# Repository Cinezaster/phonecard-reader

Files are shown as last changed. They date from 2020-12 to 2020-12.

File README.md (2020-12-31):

# Phonecard-reader

A phonecard reader that outputs the memory of a phonecard in hexadecimal via keystrokes

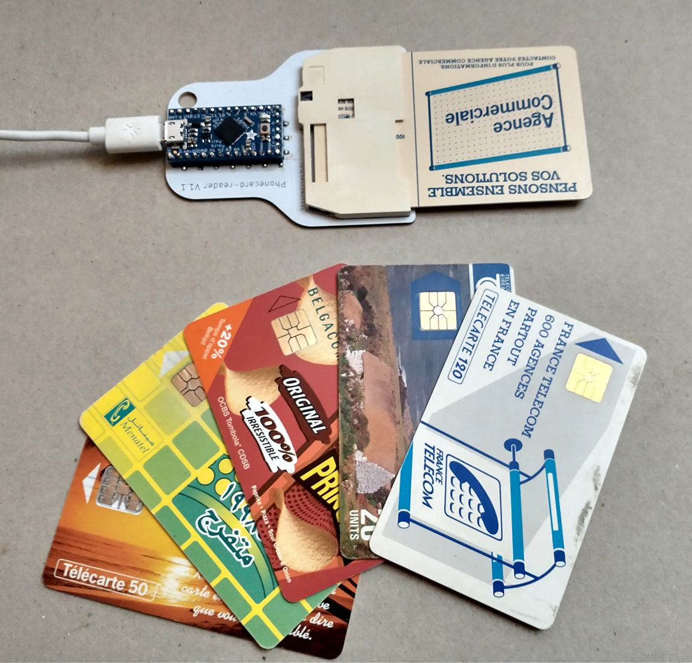
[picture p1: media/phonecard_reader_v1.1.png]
Phonecard reader pcb & cards phonecard reader & cards


## Requirements

- should read the memory of Gen 1 phonecards
- should read the memory of Gen 2 ISO 7816 phonecards
- should return the memory as a hex string to a computer or smartphone as keystrokes
- should check if memory can be read consistently

## Specs

- a 16pin card reader for iso 7816 and AFNOR type of cards: [RS-online](https://befr.rs-online.com/web/p/memory-card-connectors/0252585/)
- a 5V MCU with HID capacity like [arduino micro](https://store.arduino.cc/arduino-micro) or [Adafruit ItsyBitsy 32u4 5V](https://www.adafruit.com/product/3677)

## Hardware

A 1-Layer smd pcb.

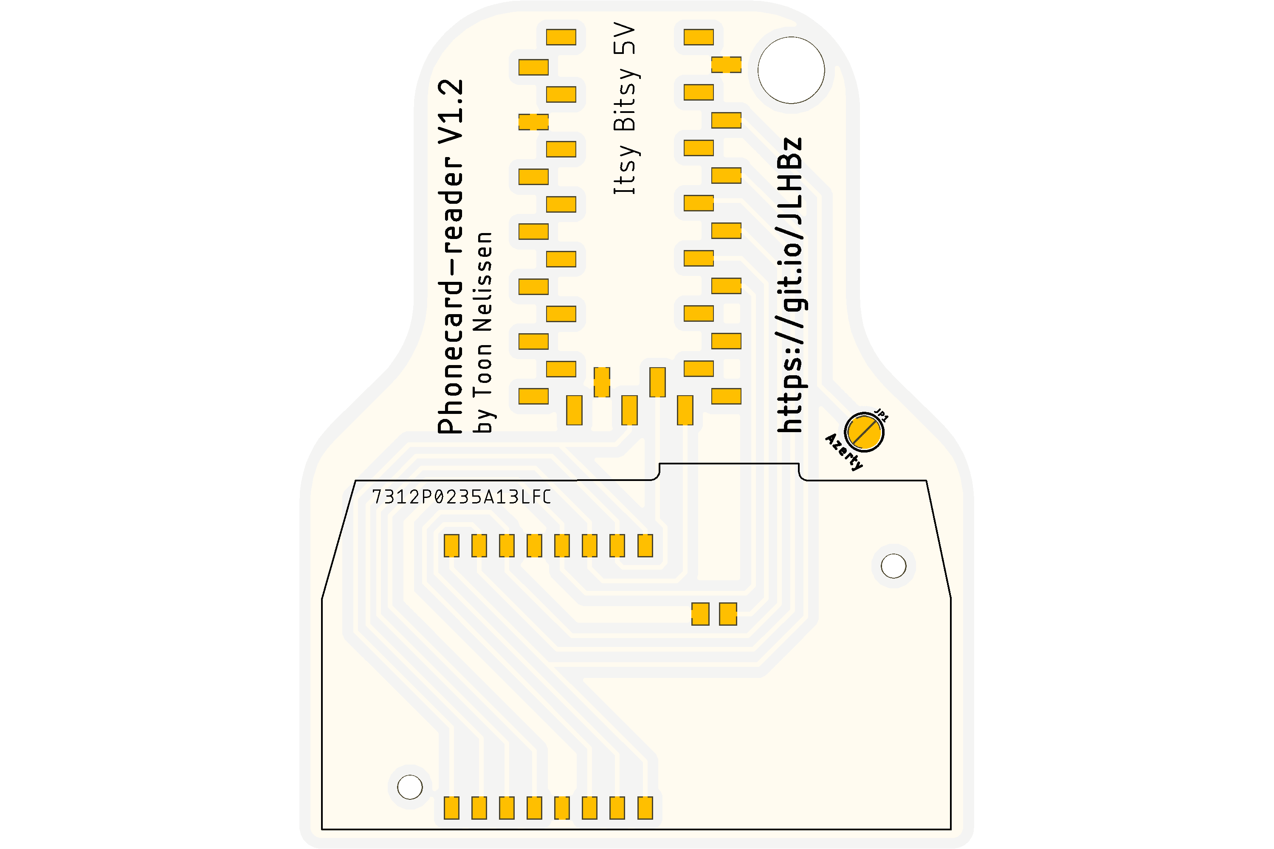
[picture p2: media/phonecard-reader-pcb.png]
Phonecard reader pcb phonecard reader pcb


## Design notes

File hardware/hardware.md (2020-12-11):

# Hardware

## MCU

Requirements are 5V and HID emulation this fits well with the **ATmega32U4**

- [Adafruit ItsyBitsy 32u4](https://www.adafruit.com/product/3677) (€8,40) *Cheapest*
- [SparkFun Qwiic Pro Micro - USB-C](https://www.sparkfun.com/products/15795) (€19) *surface mounted*
- [Teensy 2.0](https://www.pjrc.com/store/teensy.html) (€17)
- [Arduino MICRO](https://store.arduino.cc/arduino-micro) (€18)

## Card connector/ socket

We like to use a 16pin connector because of the AFNOR and ISO 7816 cards ([more info](https://www.sbprojects.net/knowledge/footprints/smart/index.php))

- [Amphenol fcicoonnect 7312P0235A13LFC](https://www.amphenol-icc.com/smart-card-7312p0235a13lf.html)

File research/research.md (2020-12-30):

# Research

## Cards spec info

- [http://www.smartcardsupply.com/Content/Cards/7816standard.htm](http://www.smartcardsupply.com/Content/Cards/7816standard.htm)
- [https://resources.infosecinstitute.com/topic/introduction-smartcard-security/](https://resources.infosecinstitute.com/topic/introduction-smartcard-security/)
- [https://github.com/arduinocodedog/Parallax-Smart-Card-Reader-Library-for-Arduino](https://github.com/arduinocodedog/Parallax-Smart-Card-Reader-Library-for-Arduino)
- [http://www.acornatom.nl/sites/oss/telkaart.htm](http://www.acornatom.nl/sites/oss/telkaart.htm)
- [https://hacktic.nl/magazine/2426.htm](https://hacktic.nl/magazine/2426.htm)
- [http://www.acbm.com/inedits/secrets-telecartes-3G.html](http://www.acbm.com/inedits/secrets-telecartes-3G.html)
- [how chips work (v1.18)](https://www.epanorama.net/documents/smartcard/how_chips_work.txt)
- [how chips work (v2.04)](www.pcbheaven.com/userpages/files/How_Phonecard_Smart_Cards_Work_3.txt)
- [http://matthieu.weber.free.fr/electronique/cartes_a_puces/index.html](http://matthieu.weber.free.fr/electronique/cartes_a_puces/index.html)
- [http://www.pcbheaven.com/userpages/How_Phonecard_Smart_Cards_Work/index.php?topic=worklog&p=0](http://www.pcbheaven.com/userpages/How_Phonecard_Smart_Cards_Work/index.php?topic=worklog&p=0)
- [http://www.tobiasfeigl.de/2015/12/23/arduino-atmel32u4-smart-card-reader-iso-7816-protocol-t1/](http://www.tobiasfeigl.de/2015/12/23/arduino-atmel32u4-smart-card-reader-iso-7816-protocol-t1/)
- [https://www.makomk.com/2011/02/25/iso-7816-smartcard-interface-for-arduino/](https://www.makomk.com/2011/02/25/iso-7816-smartcard-interface-for-arduino/)
- [http://www.smartcardsupply.com/PDF/DS_sle4432_42_0795.pdf](http://www.smartcardsupply.com/PDF/DS_sle4432_42_0795.pdf)
- [https://hackaday.com/2008/11/25/how-to-read-a-fedex-kinkos-smart-card-sle4442/](https://hackaday.com/2008/11/25/how-to-read-a-fedex-kinkos-smart-card-sle4442/)
- [http://col2000.free.fr/telecart/index.htm](http://col2000.free.fr/telecart/index.htm)
- [https://forum.arduino.cc/index.php?topic=91751.0](https://forum.arduino.cc/index.php?topic=91751.0)
- [Type of Smart Cards](https://www.sbprojects.net/knowledge/footprints/smart/index.php)

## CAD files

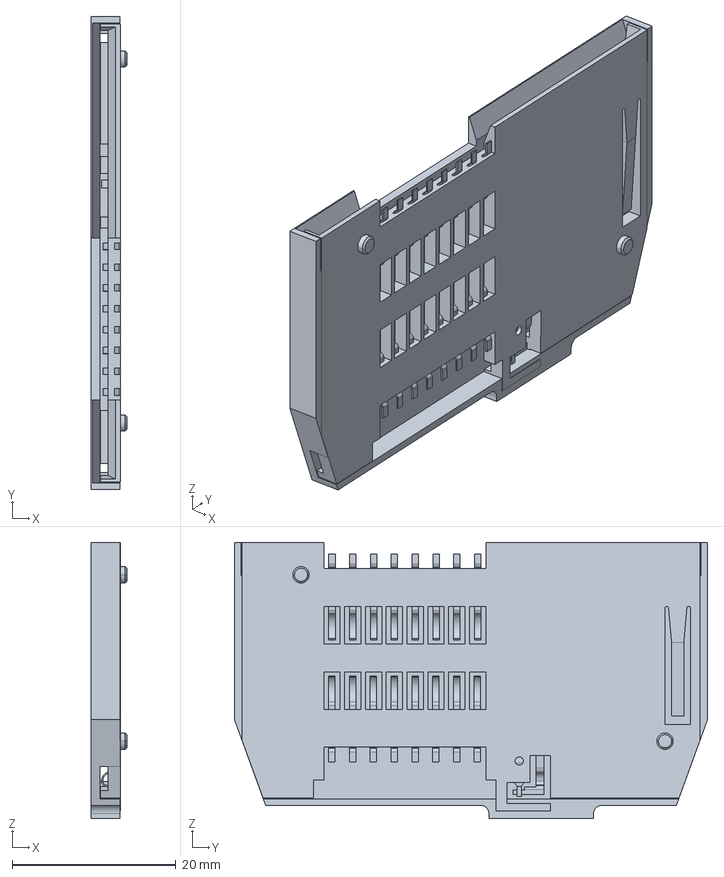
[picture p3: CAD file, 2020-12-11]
hardware/documentation/7312P0235A13LFC.stp
4.35 x 57.8 x 33.7 mm

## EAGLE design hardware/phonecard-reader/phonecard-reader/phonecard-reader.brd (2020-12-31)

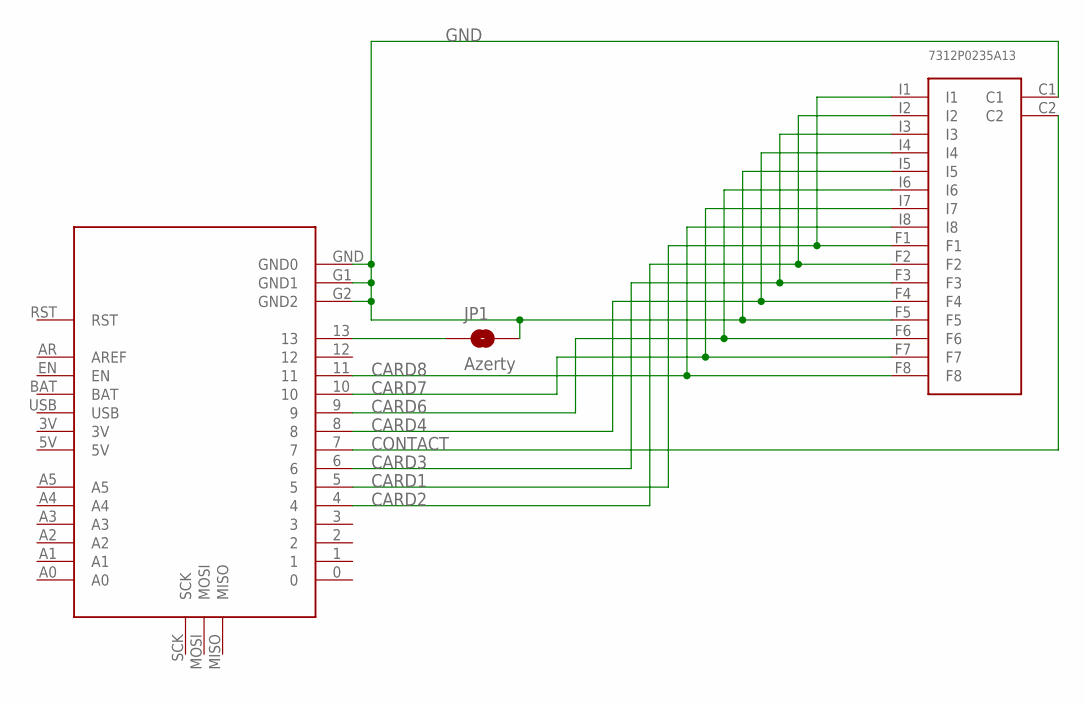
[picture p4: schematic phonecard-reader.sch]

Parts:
JP1: Azerty; SMT-JUMPER_2_NO_SILK_ROUND
U$1: Itsy Bitsy 5V; ITSY_BITSY_SMD
U$2: 7312P0235A13LFC; 7312P0235A13

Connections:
CARD1: U$1.5, U$2.F1, U$2.I1
CARD2: U$1.4, U$2.F2, U$2.I2
CARD3: U$1.6, U$2.F3, U$2.I3
CARD4: U$1.8, U$2.F4, U$2.I4
CARD6: U$1.9, U$2.F6, U$2.I6
CARD7: U$1.10, U$2.F7, U$2.I7
CARD8: U$1.11, U$2.F8, U$2.I8
CONTACT: U$1.7, U$2.C2
GND: JP1.2, U$1.G1 (GND1), U$1.G2 (GND2), U$1.GND (GND0), U$2.C1, U$2.F5, U$2.I5
unnamed: JP1.1, U$1.13

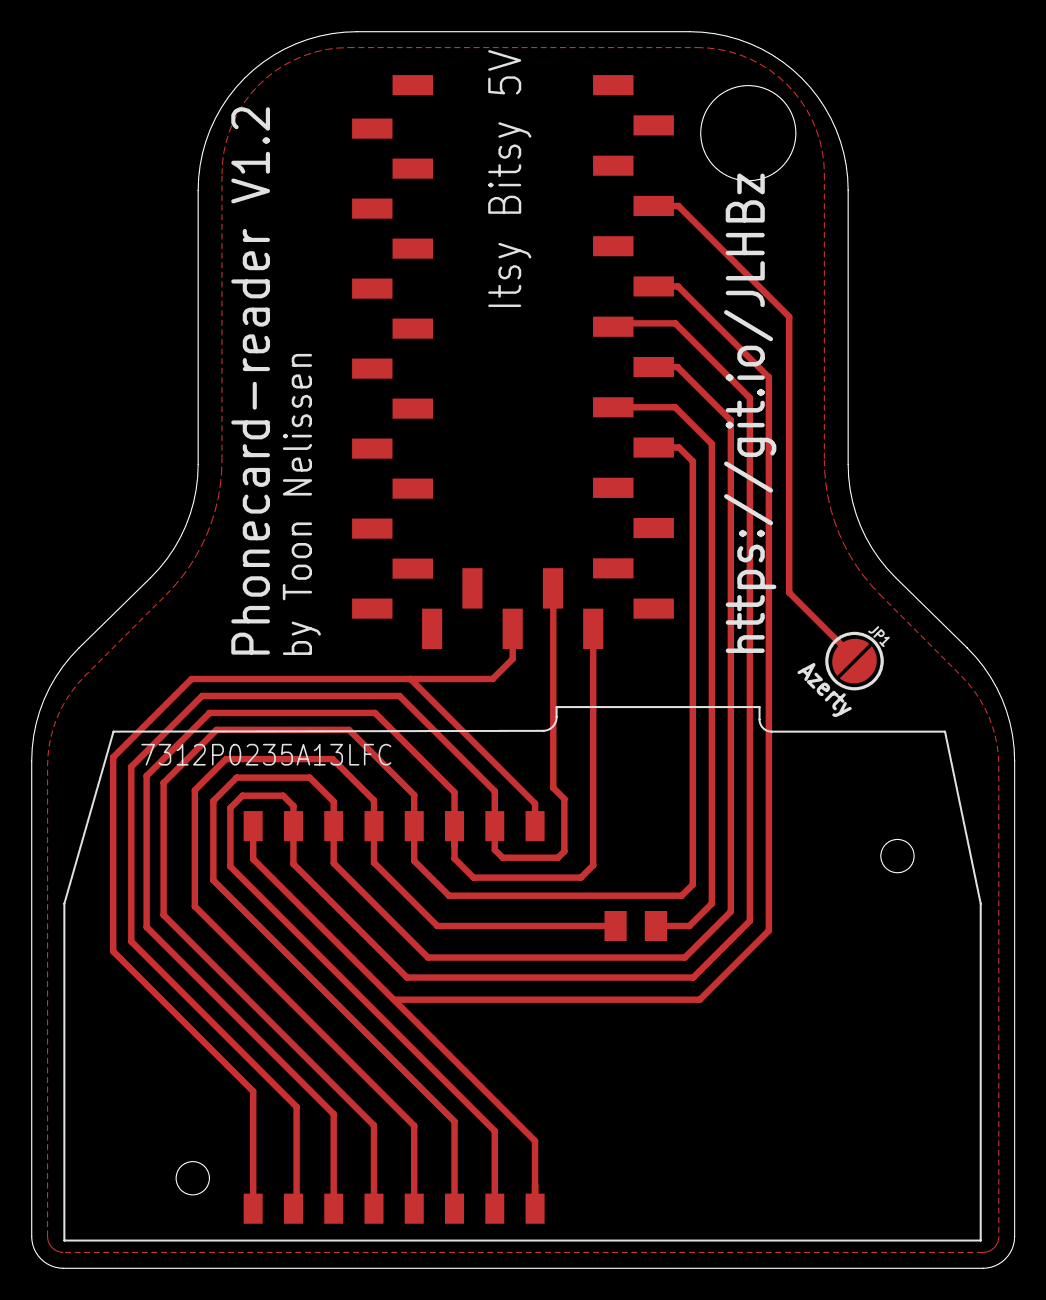
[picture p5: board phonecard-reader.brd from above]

Board: 2 copper layers, 62.0 x 78.0 mm, 3 parts (0 on the bottom side), 10 nets.

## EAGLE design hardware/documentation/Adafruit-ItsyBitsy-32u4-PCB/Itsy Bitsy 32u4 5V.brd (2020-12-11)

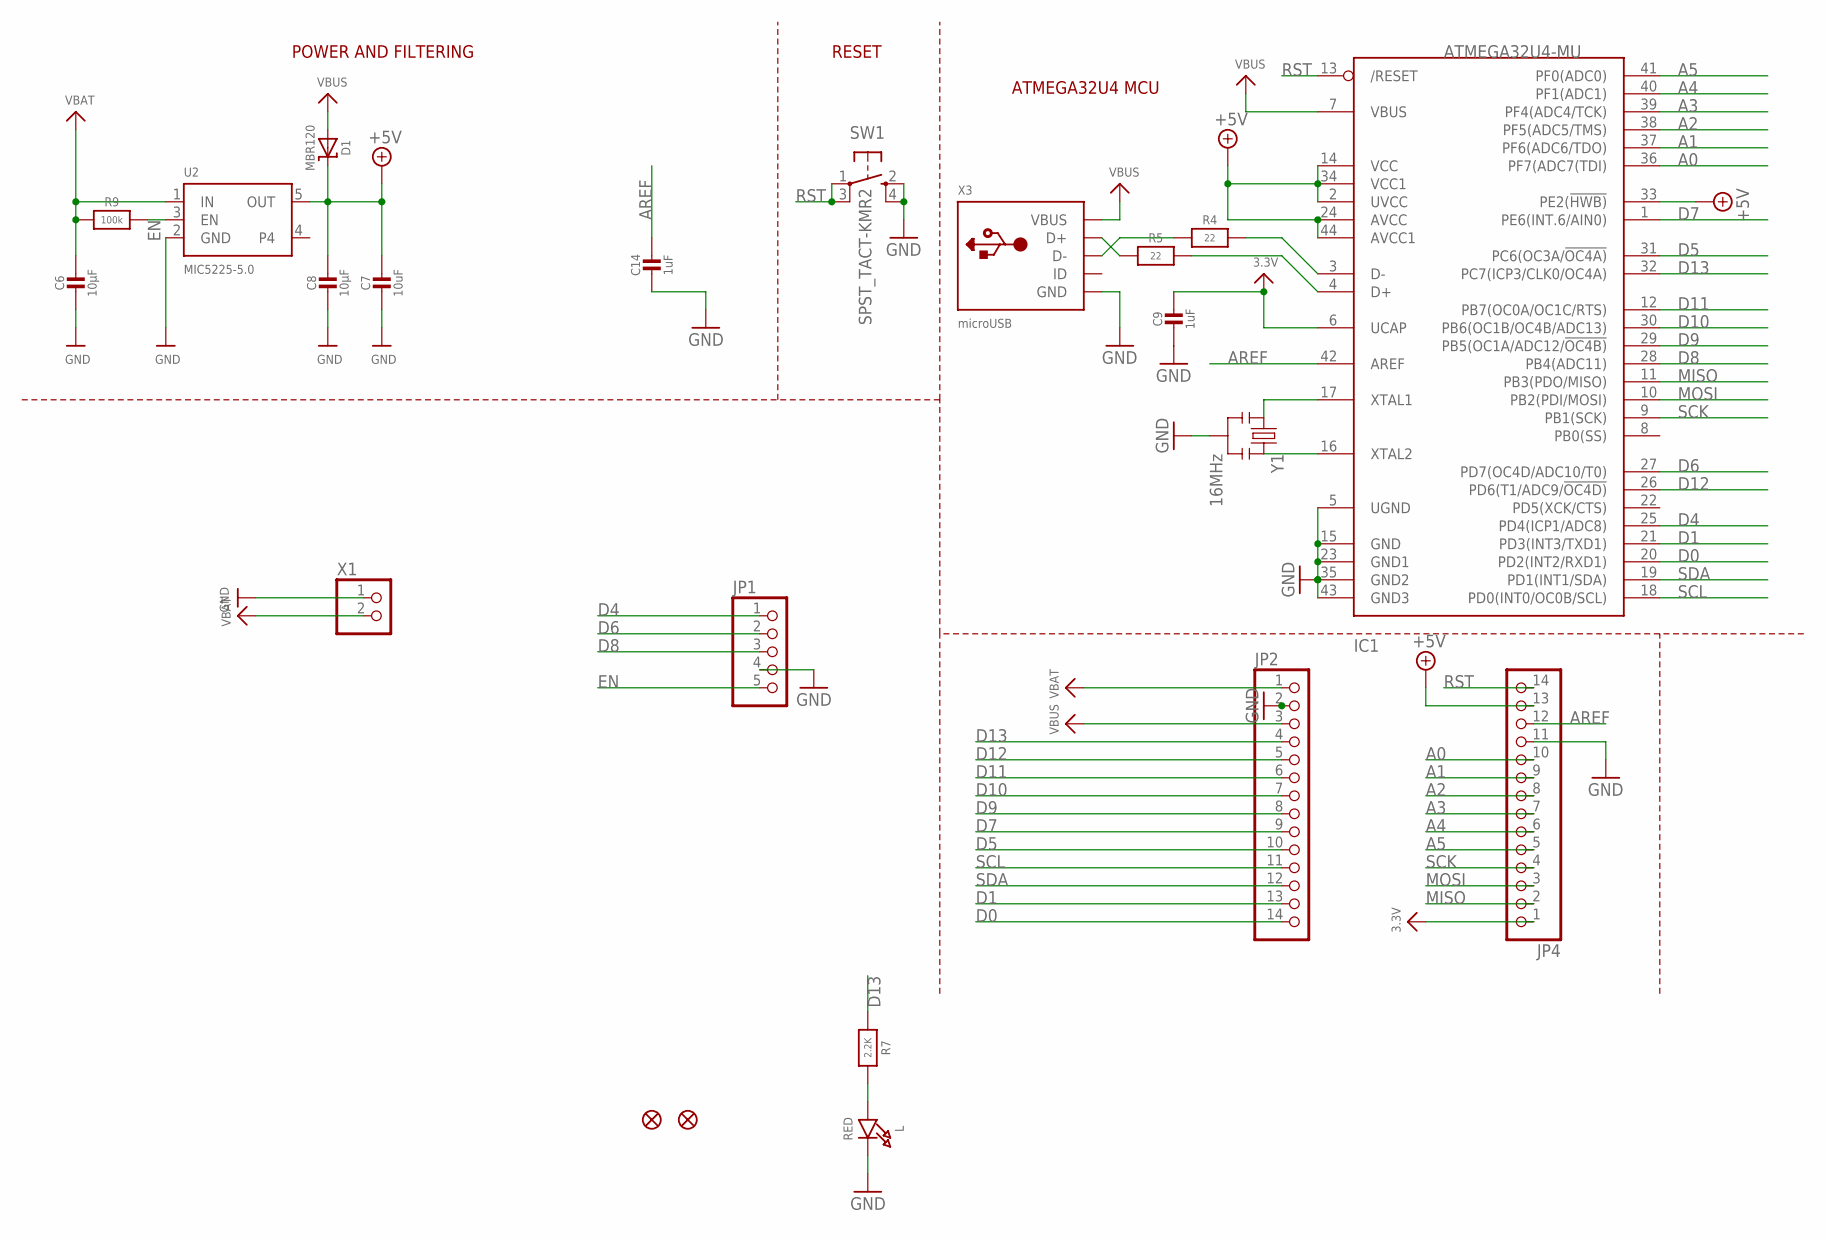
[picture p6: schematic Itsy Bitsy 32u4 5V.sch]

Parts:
C6, C8: 10µF; 0805-NO
C7: 10uF; 0805-NO
C9, C14: 1uF; 0603-NO
D1: MBR120; SOD-123
IC1: ATMEGA32U4-MU; TQFN44_7MM
JP1: HEADER-1X5ROUND; 1X05_ROUND
JP2, JP4: HEADER-1X14; 1X14_ROUND70
L: RED; CHIPLED_0805_NOOUTLINE
R4, R5: 22; 0603-NO
R7: 2.2K; 0603-NO
R9: 100k; 0603-NO
SW1: SPST_TACT-KMR2; KMR2
U2: MIC5225-5.0; SOT23-5
U$34, U$35: FIDUCIAL""; FIDUCIAL_1MM
X1: CON_JST_PH_2PIN; JSTPH2
X3: microUSB; 4UCONN_20329_V2
Y1: 16MHz; RESONATOR-SMD

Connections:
3.3V: C9.1, IC1.6 (UCAP), JP4.1
+5V: C7.1, C8.1, D1.C, IC1.2 (UVCC), IC1.14 (VCC), IC1.24 (AVCC), IC1.33 (PE2(!HWB)), IC1.34 (VCC1), IC1.44 (AVCC1), JP4.13, U2.5 (OUT)
A0: IC1.36 (PF7(ADC7(TDI)), JP4.10
A1: IC1.37 (PF6(ADC6/TDO)), JP4.9
A2: IC1.38 (PF5(ADC5/TMS)), JP4.8
A3: IC1.39 (PF4(ADC4/TCK)), JP4.7
A4: IC1.40 (PF1(ADC1)), JP4.6
A5: IC1.41 (PF0(ADC0)), JP4.5
AREF: C14.1, IC1.42 (AREF), JP4.12
D0: IC1.20 (PD2(INT2/RXD1)), JP2.14
D1: IC1.21 (PD3(INT3/TXD1)), JP2.13
D4: IC1.25 (PD4(ICP1/ADC8)), JP1.1
D5: IC1.31 (PC6(OC3A/!OC4A)), JP2.10
D6: IC1.27 (PD7(OC4D/ADC10/T0)), JP1.2
D7: IC1.1 (PE6(INT.6/AIN0)), JP2.9
D8: IC1.28 (PB4(ADC11)), JP1.3
D9: IC1.29 (PB5(OC1A/ADC12/!OC4B)), JP2.8
D10: IC1.30 (PB6(OC1B/OC4B/ADC13)), JP2.7
D11: IC1.12 (PB7(OC0A/OC1C/RTS)), JP2.6
D12: IC1.26 (PD6(T1/ADC9/!OC4D)), JP2.5
D13: IC1.32 (PC7(ICP3/CLK0/OC4A)), JP2.4, R7.1
D+: IC1.4 (D+), R5.2
D-: IC1.3 (D-), R4.2
EN: JP1.5, R9.2, U2.3 (EN)
GND: C6.2, C7.2, C8.2, C9.2, C14.2, IC1.5 (UGND), IC1.15 (GND), IC1.23 (GND1), IC1.35 (GND2), IC1.43 (GND3), JP1.4, JP2.2, JP4.11, L.C, SW1.2 (S), SW1.4 (S1), U2.2 (GND), X1.1, X3.BASE@1 (GND), X3.BASE@2 (GND), X3.GND, X3.SPRT@1 (GND), X3.SPRT@2 (GND), X3.SPRT@3 (GND), X3.SPRT@4 (GND), Y1.2
MISO: IC1.11 (PB3(PDO/MISO)), JP4.2
MOSI: IC1.10 (PB2(PDI/MOSI)), JP4.3
unnamed: L.A, R7.2
unnamed: IC1.16 (XTAL2), Y1.3
unnamed: IC1.17 (XTAL1), Y1.1
unnamed: R5.1, X3.D+
unnamed: R4.1, X3.D-
RST: IC1.13 (/RESET), JP4.14, SW1.1, SW1.3 (P1)
SCK: IC1.9 (PB1(SCK)), JP4.4
SCL: IC1.18 (PD0(INT0/OC0B/SCL)), JP2.11
SDA: IC1.19 (PD1(INT1/SDA)), JP2.12
VBAT: C6.1, JP2.1, R9.1, U2.1 (IN), X1.2
VBUS: D1.A, IC1.7 (VBUS), JP2.3, X3.VBUS

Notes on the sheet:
POWER AND FILTERING
RESET
ATMEGA32U4 MCU

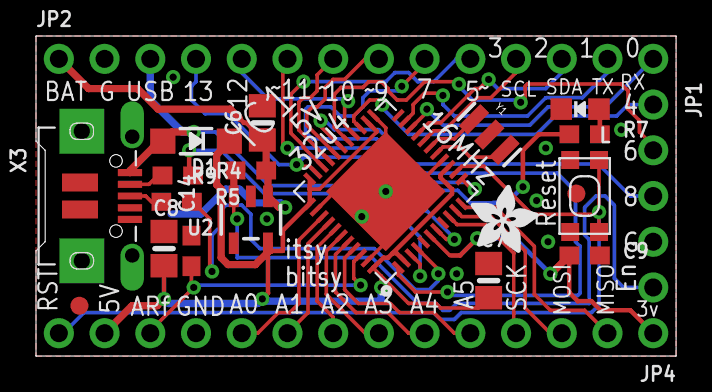
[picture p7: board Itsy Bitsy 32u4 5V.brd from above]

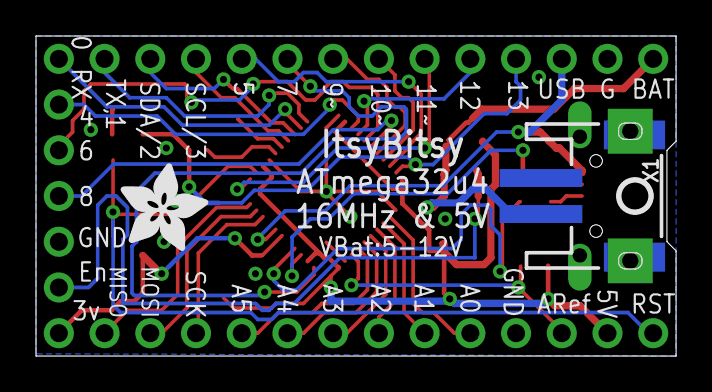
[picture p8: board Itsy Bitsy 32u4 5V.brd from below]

Board: 2 copper layers, 35.6 x 17.8 mm, 25 parts (3 on the bottom side), 38 nets.

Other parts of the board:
U$4: ADAFRUIT_5MM
U$7: ADAFRUIT_3.5MM
U$10: PCBFEAT-REV-040

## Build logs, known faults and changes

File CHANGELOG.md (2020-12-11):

# Changelog

All notable changes to this project will be documented in this file.

The format is based on [Keep a Changelog](https://keepachangelog.com/en/1.0.0/),
and this project adheres to [Semantic Versioning](https://semver.org/spec/v2.0.0.html).

## [Unreleased]

## [0.0.1] - 2020-12-11

### Added

- Hardware component documentation
- Research
- Initial firmware

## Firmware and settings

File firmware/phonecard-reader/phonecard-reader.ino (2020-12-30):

#include <Bounce2.h>
#include "Keyboard.h"

#define CARD_PIN_1 5
#define CARD_PIN_2 4
#define CARD_PIN_3 6
#define CARD_PIN_4 8
#define CARD_PIN_6 9
#define CARD_PIN_7 10
#define CARD_PIN_8 11
#define BUTTON_PIN 7
#define LED_PIN 13

// Instantiate a Bounce object :
Bounce debouncer = Bounce();

byte memMap[32];
char tmp[2];
byte sum;
byte calculated_sum;
int val = 0;
int VCC, R_W, CLK, RST, GND, VPP, IO, FUSE, NC1, NC2;

void relaxPinState () {
  int pins[7] = {4, 5, 6, 8, 9, 10, 11};
  for (int i = 0; i < 7; i++) {
    pinMode(pins[i], INPUT);
  }
}

void readGenOneCard ( ) {
  VCC = CARD_PIN_1;
  pinMode(VCC, OUTPUT);
  digitalWrite(VCC, 1);

  R_W = CARD_PIN_2;
  pinMode(R_W, OUTPUT);
  digitalWrite(R_W, 0);

  CLK = CARD_PIN_3;
  pinMode(CLK, OUTPUT);
  digitalWrite(CLK, 0);

  RST = CARD_PIN_4;
  pinMode(RST, OUTPUT);
  digitalWrite(RST, 1);

  VPP = CARD_PIN_6;
  pinMode(VPP, OUTPUT);
  digitalWrite(VPP, 1);

  IO = CARD_PIN_7;
  pinMode(IO, INPUT);

  FUSE = CARD_PIN_8;
  pinMode(FUSE, INPUT);

  digitalWrite(RST, 0);
  delay(1);
  digitalWrite(CLK, 1);
  delay(1);
  digitalWrite(CLK, 0);

  digitalWrite(RST, 1);

  sum = 0;
  for (int i = 0; i < 32; i++) {
    byte memByte = 0b00000000;
    for (int j = 7; j > -1; j--) {
      val = digitalRead(IO);
      bitWrite(memByte, j, val);
      digitalWrite(CLK, 1);
      delay(1);
      digitalWrite(CLK, 0);
    }
    memMap[i] = memByte;
    sum += memByte;
  }

  relaxPinState();
}

void readGenTwoCard () {
  VCC = CARD_PIN_1;
  pinMode(VCC, OUTPUT);
  digitalWrite(VCC, 0);

  RST = CARD_PIN_2;
  pinMode(RST, OUTPUT);
  digitalWrite(RST, 0);

  CLK = CARD_PIN_3;
  pinMode(CLK, OUTPUT);
  digitalWrite(CLK, 0);

  NC1 = CARD_PIN_4;
  pinMode(NC1, OUTPUT);
  digitalWrite(NC1, 0);

  VPP = CARD_PIN_6;
  pinMode(VPP, OUTPUT);
  digitalWrite(VPP, 0);

  IO = CARD_PIN_7;
  pinMode(IO, INPUT_PULLUP);

  NC2 = CARD_PIN_8;
  pinMode(NC2, OUTPUT);
  digitalWrite(NC2, 0);

  digitalWrite(VCC, 1);
  digitalWrite(VPP, 1);

  delay(1);

  // to take care the counter is in possition range of 0 to 7
  for (int i = 0; i < 8; i++) {
    digitalWrite(CLK, 1);
    delay(1);
    digitalWrite(CLK, 0);
    delay(1);
  }
  digitalWrite(RST, 1);
  delay(1);
  digitalWrite(CLK, 1);
  delay(1);
  digitalWrite(CLK, 0);
  delay(1);
  digitalWrite(RST, 0);
  delay(1);


  sum = 0;
  for (int i = 0; i < 32; i++) {
    byte memByte = 0b00000000;
    for (int j = 7; j > -1; j--) {

      val = digitalRead(IO);
      bitWrite(memByte, j, val);
      digitalWrite(CLK, 1);
      delay(1);
      digitalWrite(CLK, 0);
    }
    memMap[i] = memByte;
    sum += memMap[i];
  }

  relaxPinState();
}

void setup() {
  //Serial.begin(9600);
  Keyboard.begin();
  // Setup the button with an internal pull-up :
  pinMode(BUTTON_PIN, INPUT_PULLUP);

  // After setting up the button, setup the Bounce instance :
  debouncer.attach(BUTTON_PIN);
  debouncer.interval(25);

  // Setup the LED :
  pinMode(LED_PIN, OUTPUT);
  digitalWrite(LED_PIN, LOW);

  relaxPinState();
}

bool check (byte checksum) {
  calculated_sum = -checksum;
  return (calculated_sum < 0xFF && calculated_sum > 0 && calculated_sum != 0x20) ;
}

void printHex () {
  for (int i = 0; i < 32; i++) {
    sprintf(tmp, "%.2X", memMap[i]);
    for (int j = 0; j < 2; j++) {
      Keyboard.print(tmp[j]);
    }
  }
  Keyboard.println("");
}

void loop() {

  // Update the Bounce instance :
  debouncer.update();

  // Call code if Bounce fell (transition from HIGH to LOW) :
  if ( debouncer.fell() ) {
    digitalWrite(LED_PIN, HIGH);
    int testSum;
    readGenOneCard();
    testSum = sum;
    readGenOneCard();
    if (testSum == int(sum) && check(sum)) {
      printHex();
    } else {
      readGenTwoCard();
      testSum = sum;
      readGenTwoCard();
      if (testSum == int(sum) && check(sum)) {
        printHex();
      }
    }
    digitalWrite(LED_PIN, LOW);
  }
}

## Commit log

2020-12-11 feat: firmware
    [7312P0235A13LFC.stp, Itsy Bitsy 32u4 3V.brd, Itsy Bitsy 32u4 3V.sch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]
2020-12-30 docs: add card footprints
2020-12-30 feat: add hardware schematics and board
    [phonecard-reader.brd, phonecard-reader.sch]
2020-12-30 feat: added azerty keyboard output jumper to pcb
    [phonecard-reader.brd, phonecard-reader.sch]
2020-12-31 feat: update keyboard switch pin
    [phonecard-reader.brd, phonecard-reader.sch]

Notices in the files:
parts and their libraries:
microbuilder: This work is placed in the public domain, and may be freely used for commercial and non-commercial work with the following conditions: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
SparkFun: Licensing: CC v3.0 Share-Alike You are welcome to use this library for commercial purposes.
